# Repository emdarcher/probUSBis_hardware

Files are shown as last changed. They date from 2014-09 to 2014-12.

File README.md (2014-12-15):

probUSBis Hardware
==================

Hardware files for probUSBis board.

This board is heavily inspired and based off of the [LittleWire](http://littlewire.cc/) and 
[DigiSpark](http://digistump.com/products/1) projects, with some little features of my own added to it.

The files are being made in KiCAD, but PDFs of the schematics will be made for releases.

Link to the [Hackaday Projects page](http://hackaday.io/project/3035) for this thing.

I have also made some code to run on this board in my [probUSBis_programs](https://github.com/emdarcher/probUSBis_programs) repository.

here is an image of the rev_a1 schamatic:
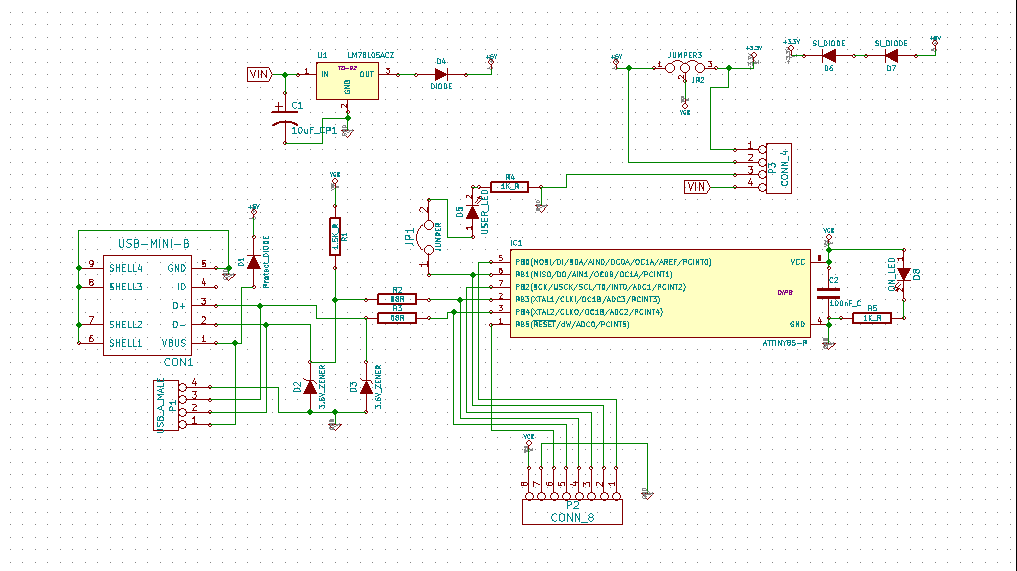
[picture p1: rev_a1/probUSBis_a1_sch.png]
rev_a1_schematic


##WARNING!
* __rev_a1__ has a serious PCB error! The layout for the USB_A_MALE connector is flipped due to accidentally using a female layout. 
  - Solutions: 
    - if you still want a male USB plug on the board, you can solder it upside down, with pins sticking up into the bottom of the board.
    - Just don't use a male USB plug, and solder a suface mount female mini USB B jack on the top of the board in the designated location.

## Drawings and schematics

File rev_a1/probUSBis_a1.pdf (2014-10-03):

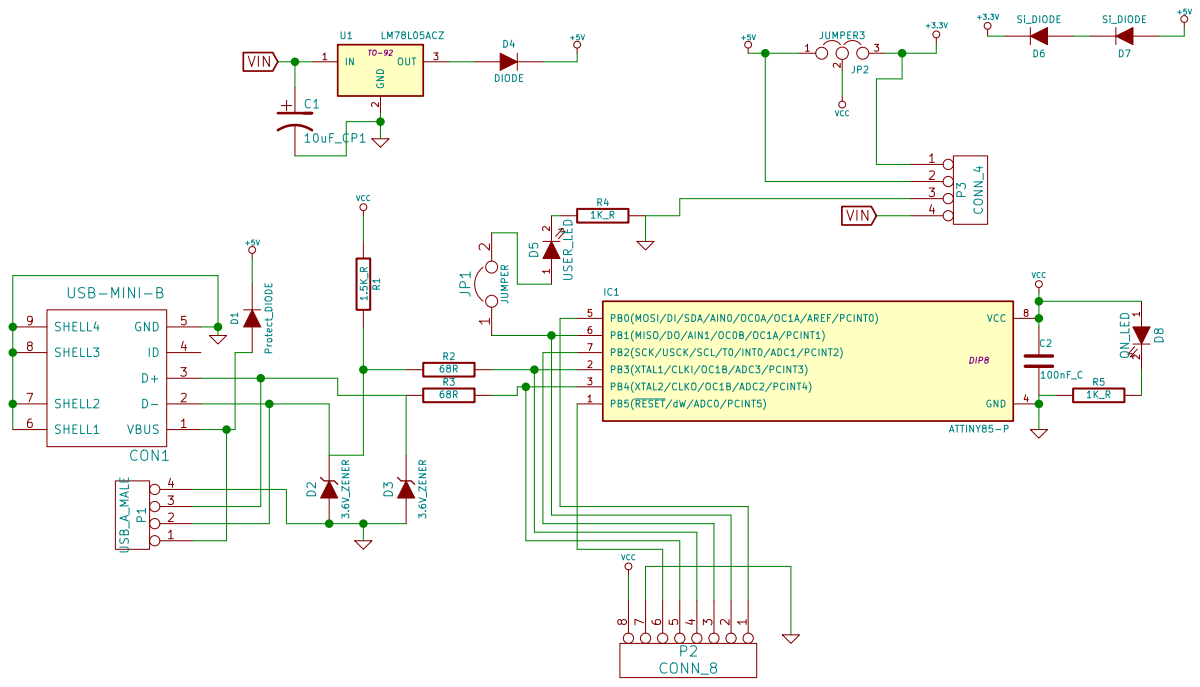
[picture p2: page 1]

C Durrantics Sheet: /home/sethan/Documents/electronics-robotics/business/git-repos/git-cad/probUSBis_hardware/rev_a1/probUSBis_a1.sch File: Title: probUSBis_a1

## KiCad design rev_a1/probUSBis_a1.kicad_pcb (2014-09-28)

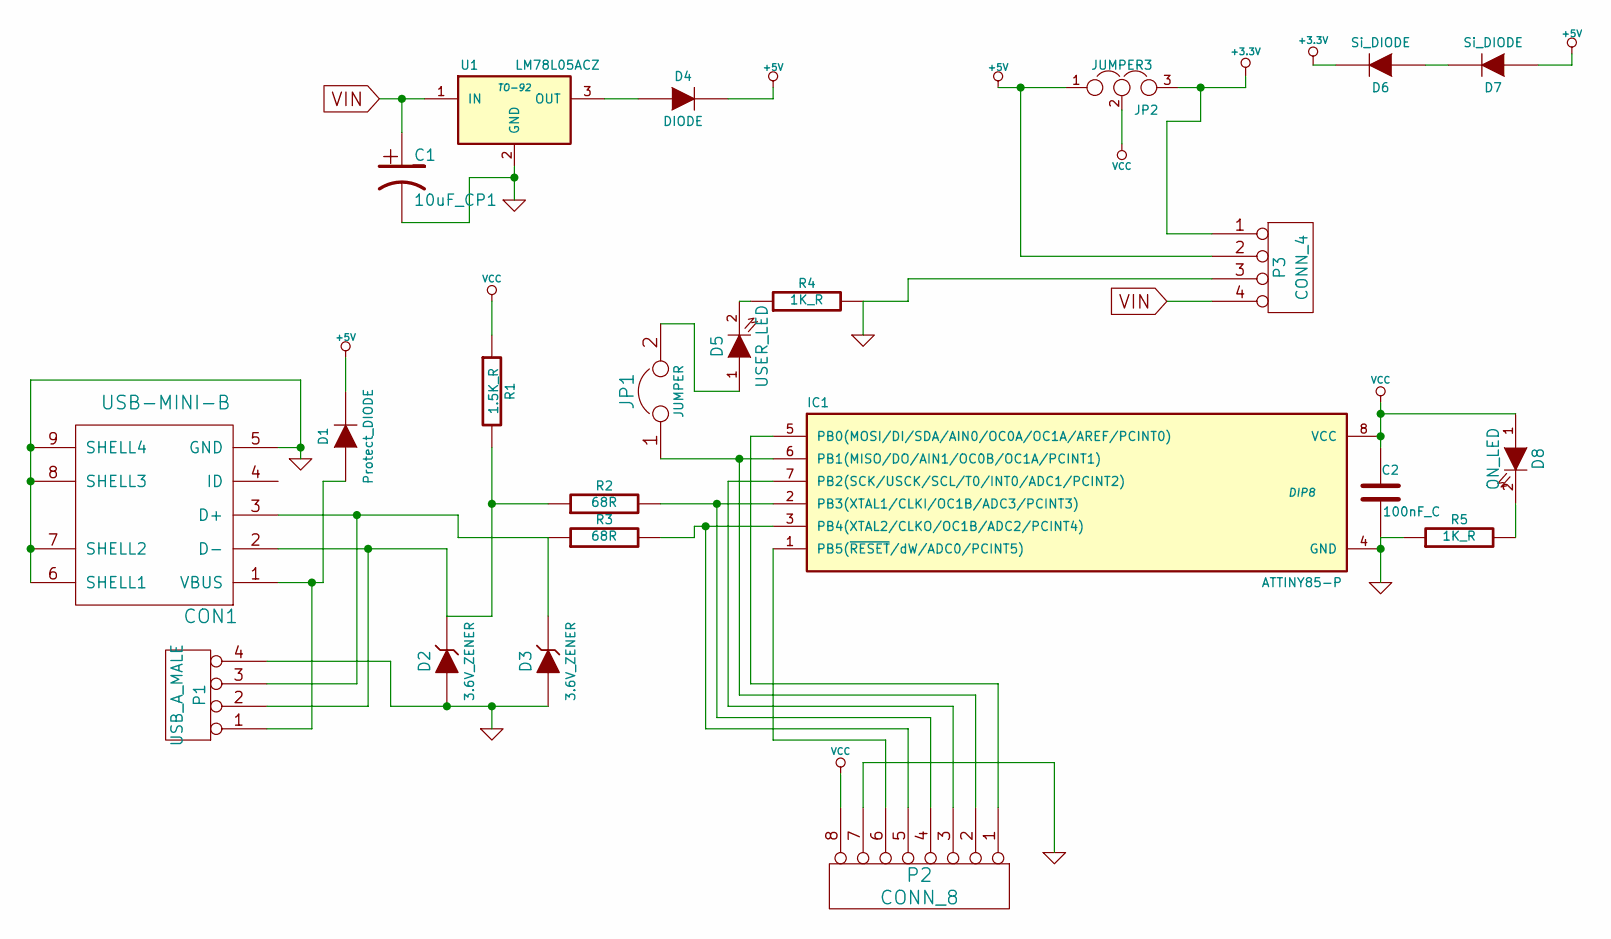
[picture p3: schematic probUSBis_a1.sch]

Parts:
C1: 10uF_CP1
C2: 100nF_C
CON1: USB-MINI-B
D1: Protect_DIODE
D2, D3: 3.6V_ZENER
D4: DIODE
D5: USER_LED
D6, D7: Si_DIODE
D8: ON_LED
IC1: ATTINY85-P; DIP8
JP1: JUMPER
JP2: JUMPER3
P1: USB_A_MALE
P2: CONN_8
P3: CONN_4
R1: 1.5K_R
R2, R3: 68R
R4, R5: 1K_R
U1: LM78L05ACZ; TO-92

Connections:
+3.3V: D6.2 (K), JP2.3, P3.1
+5V: D1.2 (K), D4.2 (K), D7.1 (A), JP2.1, P3.2
GND: C1.2, C2.2, CON1.5 (GND), CON1.6 (SHELL1), CON1.7 (SHELL2), CON1.8 (SHELL3), CON1.9 (SHELL4), D2.1 (A), D3.1 (A), IC1.4 (GND), P1.4, P2.7, P3.3, R4.2, R5.1, U1.2 (GND)
unnamed: IC1.1 (PB5(~RESET~/dW/ADC0/PCINT5)), P2.6
unnamed: CON1.1 (VBUS), D1.1 (A), P1.1
unnamed: IC1.5 (PB0(MOSI/DI/SDA/AIN0/OC0A/OC1A/AREF/PCI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), P2.1
unnamed: IC1.6 (PB1(MISO/DO/AIN1/OC0B/OC1A/PCINT1)), JP1.1, P2.2
unnamed: IC1.7 (PB2(SCK/USCK/SCL/T0/INT0/ADC1/PCINT2)), P2.3
unnamed: D8.2 (K), R5.2
unnamed: D5.1 (A), JP1.2
unnamed: D5.2 (K), R4.1
unnamed: D6.1 (A), D7.2 (K)
unnamed: IC1.3 (PB4(XTAL2/CLKO/OC1B/ADC2/PCINT4)), P2.5, R3.2
unnamed: D4.1 (A), U1.3 (OUT)
unnamed: CON1.3 (D+), D3.2 (K), P1.3, R3.1
unnamed: CON1.2 (D-), D2.2 (K), P1.2, R1.2, R2.1
unnamed: IC1.2 (PB3(XTAL1/CLKI/OC1B/ADC3/PCINT3)), P2.4, R2.2
VCC: C2.1, D8.1 (A), IC1.8 (VCC), JP2.2, P2.8, R1.1
VIN: C1.1, P3.4, U1.1 (IN)

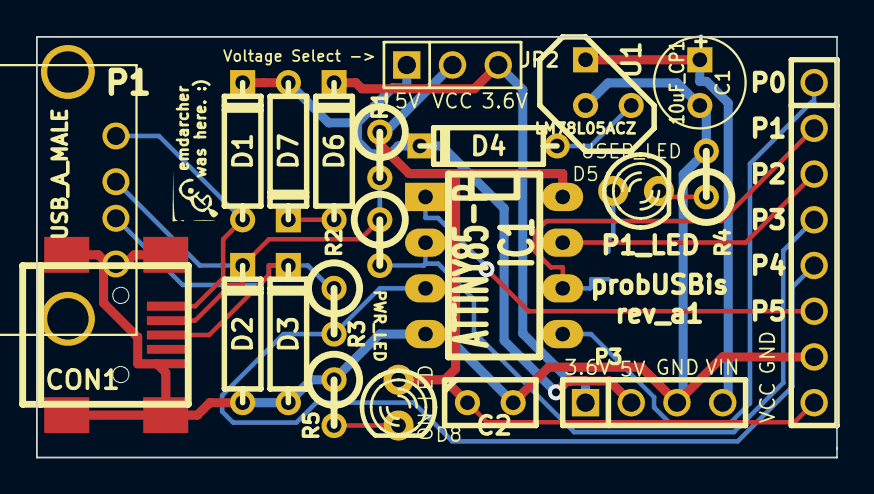
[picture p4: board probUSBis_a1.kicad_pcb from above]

Board: 2 copper layers, 44.5 x 23.4 mm, 23 parts (1 on the bottom side), 19 nets.

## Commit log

2014-09-02 first commit, started kicad project and made readme
2014-09-03 made schematic, mostly done with it
    [probUSBis_a1.sch]
2014-09-03 moved a1 files to a separate folder
    [probUSBis_a1.sch]
2014-09-03 added jumper for user led on PB1
    [probUSBis_a1.sch]
2014-09-03 made netlist
    [probUSBis_a1.sch]
2014-09-03 did first setup of footprints for parts
2014-09-04 did some random pcb stuff
    [probUSBis_a1.kicad_pcb]
2014-09-05 made some changes to pcb, added cut edge
    [probUSBis_a1.kicad_pcb]
2014-09-05 made dsn, also making pin labels
    [probUSBis_a1.dsn, probUSBis_a1.kicad_pcb]
2014-09-05 editing pcb layout, trying to compress more
    [probUSBis_a1.kicad_pcb]
2014-09-05 moving usb around, fiddling with the pcb
    [probUSBis_a1.kicad_pcb]
2014-09-05 moved stuff around, fixed 5v ref layout
    [probUSBis_a1.dsn, probUSBis_a1.kicad_pcb]
2014-09-15 did some routing with freerouter
    [probUSBis_a1.dsn, probUSBis_a1.kicad_pcb]
2014-09-16 adding more info to back silkscreen
    [probUSBis_a1.kicad_pcb]
2014-09-16 added logo on back of pcb, flipped
    [probUSBis_a1.kicad_pcb]
2014-09-16 added oshw logo to board
    [probUSBis_a1.kicad_pcb]
2014-09-16 added a ground fill
    [probUSBis_a1.kicad_pcb]
2014-09-16 made gerber and drill files for production
    [probUSBis_a1.kicad_pcb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]
2014-09-16 silkscreen stuff, editing part label locations
    [probUSBis_a1.kicad_pcb]
2014-09-16 saved pcb, redid the gerber files. did some jixes to silkscreen names
    [probUSBis_a1.kicad_pcb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]
2014-09-17 generating files
    [probUSBis_a1-B_Cu.gbl, probUSBis_a1-B_Mask.gbs, probUSBis_a1-B_SilkS.gbo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]
2014-09-18 put stuff in a folder to make zip for OSHPark
    [probUSBis_a1-B_Cu.gbl, probUSBis_a1-B_Mask.gbs, probUSBis_a1-B_SilkS.gbo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]
2014-09-28 made some holes bigger, and made new pin modules to do so.
    [probUSBis_a1.kicad_pcb]
2014-09-28 re-did the gerbers and drill files
    [probUSBis_a1-B_Cu.gbl, probUSBis_a1-B_Mask.gbs, probUSBis_a1-B_SilkS.gbo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]
2014-10-03 fixing some stuff, making schematic pdf
